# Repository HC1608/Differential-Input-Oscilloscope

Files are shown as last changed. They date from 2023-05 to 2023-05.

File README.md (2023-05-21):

# Differential-Input-Oscilloscope
Unlike a single-ended oscilloscope which can measure only the potential difference between the Ground and a node, it can measure the voltage difference between any two nodes and significant work has been done to make a current sensor that does not draw any current into it.
It is highly portable and can work using normal 5V mobile charger.

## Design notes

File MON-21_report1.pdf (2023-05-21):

# DSO

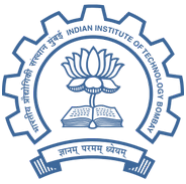
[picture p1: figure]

# Design Review Report

## EE344: Electronic Design Lab

## Faculty Mentor: Prof. PC Pandey Faculty Mentor: Prof. Joseph John

Group: MON-21
TA/RA Guide: Sanskar, Omkar

Group members:
1) Harsh Choudhary (200070023)
2) Harsh Lulla (200070024)
3) Abhinav Ghunawat (200070002)

# Index

Particulars | Page no.
Goal | 3
Block diagram | 4
Work Distribution | 5
Common b/w different groups | 6
Differences among different groups | 6
Bill of material | 7

### EE344 Electronic Design Lab Project Report, EE Dept, IIT Bombay

## 1)Description of Design

### 1.1 Goal of the project

The purpose of this project is to build a two-channel oscilloscope. This oscilloscope would then be interfaced with an application via Bluetooth/Wi-Fi to see the input waveforms inside
the application. The oscilloscope would have protection circuits to prevent voltage and current from going beyond a certain threshold for the safety of the equipment. It would use the ADC of the microcontroller to convert the analog signals to the digital domain. It would also have scaling circuits to appropriately scale up(or down) the signal for display. Finally, it would be connected to a microcontroller and the module to send
the samples to the application. The application would display the waveform along with the
amplitude and frequency. There would be additional circuitry for triggering as well.
We plan to demonstrate that our oscilloscope can display the supplied signals with proper scaling and triggering on the laptop.

### 1.2 Block Diagram

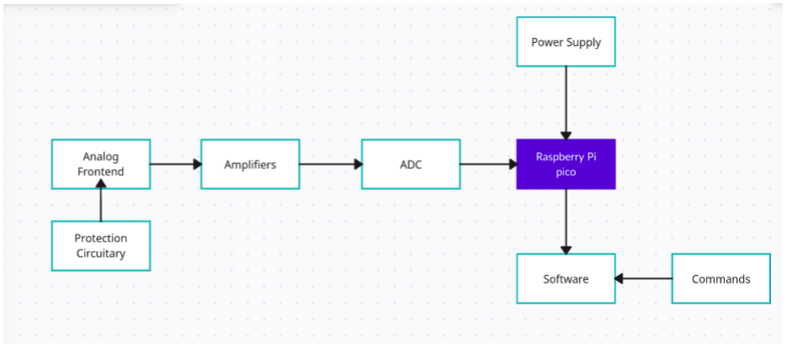
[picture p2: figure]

## 2)Project Description

Description of various parts of the project is as follows:

### 2.1 Input

Measurements shall be taken using a standard BNC connector probe as used for DSOs. Hence, a probe receptacle shall be used to connect to the probe. The standard Input impedance of almost 1MΩ and 120pF in parallel shall be connected.
- For measuring differential voltage we would be using a probe with 3 wires( positive, negative, and ground). Here, the user will have to connect it to the ground separately and there will be two such voltage probes.
- For measuring differential current we would be using probes each with 2 wires (positive and negative)

### 2.2 Protection circuit

A zener diode with necessary breakdown voltage connected back to back across the input terminals can be used for overvoltage protection. Overcurrent protection can be implemented using elements as simple as a Fuse of appropriate rating once the total current required is calculated for the entire circuit.

- We have selected the 1N4733A Zener diode to protect the circuit from voltages more than 20V
- We will be using Fuse which would protect the circuit from higher currents.

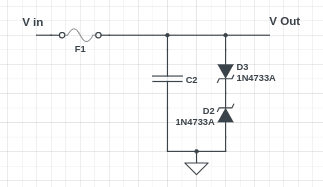
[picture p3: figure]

Figure: Protection Circuit

### 2.3 I-to-V conversion

We will use INA210 for this purpose, it is a bidirectional high-precision current sense amplifier, meaning it can measure both positive and negative currents. They have differential input pins (INA+ and INA-) for the current source and provide a voltage output proportional to the input current. It takes input power supply from 2.7V to 26V.
So, we have decided the following circuitry with Vout = (IRs)xGain + Vref

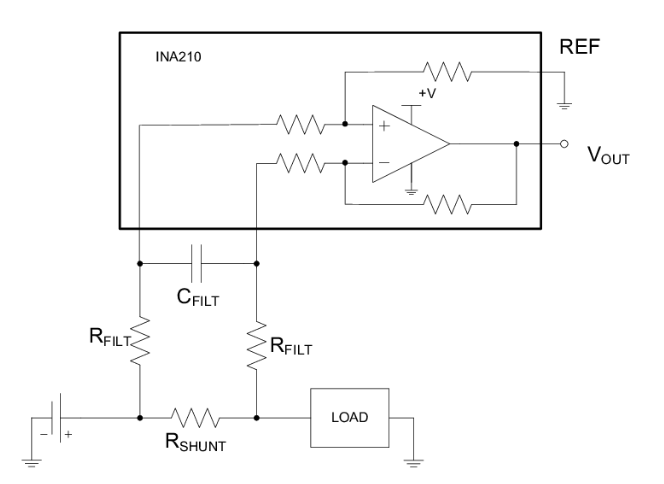
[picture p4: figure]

Figure: Bi-directional I to V conversion using INA210

### 2.4 Scaling

We have planned to use an instrumentation amplifier for amplification and to take the difference of two voltages. INA326 can be used for this purpose. It is a precision instrumentation amplifier and works with a single-sided source voltage of 5V. Its gain is given by (R3/R2)((2R1+Rgain)/Rgain).

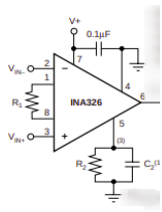
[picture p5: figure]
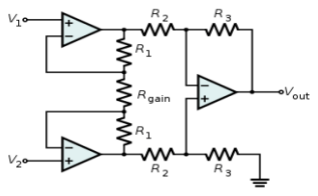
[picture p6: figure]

Figure: Instrumentation Amplifier | Figure: INA326 Circuit

X, Y Scaling will be done using hardware and not software as software receives values converted using ADC and thus it has quantization error. Further scaling it would scale up the error term also.
The value of gain will be transmitted from the software to the microcontroller and it will vary the scaling factor in the hardware accordingly.

### 2.5 Microcontroller

Microcontroller will be used for transmitting the signal from hardware to software using a wireless medium (Bluetooth/Wi-Fi) or using wire. First, it will convert analog input from the hardware to digital. Also, the Computer will communicate values of X-scale, Y-scale, and channel settings to the microcontroller, based on them, it will set the gain of the amplifier and control the multiplexer to give values of the required channels to ADC.

We have decided to use Raspberry Pi Pico for this purpose
- We will be providing power to the microcontroller using a mobile phone charger
- It has an in-built 12-bit SAR type ADC. Hence, the digital value between 0-4095 will be mapped to analog values.
- Communication will be bi-directional (in duplex mode), we will use Bluetooth/Wi-Fi/Type-C cable for connecting the devices.
- It is a dual-core Arm Cortex-M0+ processor and provides flexible clock and power management.
- The board features 26 GPIO pins, including 2 analog inputs, 2 pulse width modulation (PWM) outputs, and 2 serial peripheral interface (SPI) interfaces
- It supports microPython, which is python library made for microcontrollers

### 2.6 Triggering and Frequency Detection

We will initially do edge triggering and later as per the availability of time we can implement more triggers and also can use algorithms like peak detector or level crossing for frequency detection in sinusoidal and square waves as an additional feature.

### 2.7 Power Management

- We will supply power to the microcontroller using an adapter.
- To save power, we will transmit a signal from the multiplexer to the ADC only when it is turned from the

software.

### 2.8 Interfacing Application

We are planning to use an application based on python. Data will be received from Bluetooth/Wi-fi and would be processed to reconstruct the given signal. The triggering mechanism will be applied from the software itself and other features which will be implemented are:
1. Voltage-scaling (Sending gain value from GUI to the microcontroller)
2. Time Scaling
3. Trigger-Mode
4. X and Y Shift
5. Voltage/Current mode Selector

## 3. Weekly Targets and work distribution

The work distribution according to past experience and interest will be Harsh Choudhary for analog and software, Harsh Lulla for microcontroller and analog, and Abhinav for PCB and packaging. Power Management will be handled by all three of us.

A tentative schedule for throughout the semester is as follows:

1. Week 1: February 1 - February 7
We will have submitted the bill of materials and the components will be procured this week. Meanwhile, we will start with the schematic circuit diagrams for the ADC data transfer and the USB+Bluetooth interfacing with the microcontroller. We will also design the protection circuitry
2. Week 2: February 8 - February 14
After sourcing the components, we will start building the basic analog protection circuit, and we will work on the circuit that amplifies and attenuates the input signal. We will build the I-V conversion circuit on the breadboard. Harsh L will work on USB and Bluetooth interfacing with the microcontroller.
- Milestone: February 15 - Schematics and preliminary analysis(breadboard) review
3. Week 3: February 28 – March 6
Harsh L will start interfacing the Pico with the laptop and the ADC conversion of the signals. We will primarily work on wireless communication through Bluetooth and wired communication using USB. Harsh C will start creating the translation and scaling features on the oscilloscope display. Abhinav will initialize the work on the PCB design. We will all work on studying the different conditions the DSO will be subject to in various current and voltage applications.
4. Week 4: March 7 – March 13
Harsh L will work on the anti-aliasing filter circuit which will incorporate the sampling rate set by the user to remove higher frequency noise on the display. Harsh C will work on interpreting the signal data on the display. Abhinav will work on estimating the power consumption of the circuit and finalize the PCB design.
- Milestone: March 15 - Schematics and preliminary analysis(breadboard) review
5. Week 5: March 16 – March 22
We will collectively design packaging for the PCB design and start wrapping up the documentation of the final product. We will test the product under different conditions and make sure each subsystem is working nominally.
- Milestone: March 24 – Initial subsystem testing review – 1
- Milestone: April 5 – Individual subsystem testing review - 2

## 4. Common and different between groups

The additional feature which our group is implementing is an anti-aliasing filter which uses the Nyquist criteria to filter out higher frequency components of the differential signal. This is a challenging task as this requires us to set the cut-off frequency of the bandpass filter to be variable as the sample rate itself is variable. We will need to build an active low-pass filter circuit with variable cut-off frequency for this task.

There are two other groups doing the same project. We will collectively discuss and build upon each other’s shortcomings. Our basic hardware circuit should be similar to the ones developed by the other groups.

One group is implementing the auto-set feature. This automatically adjusts the x-scale and y-scale based on the input signals applied, and the other group is implementing reverse Nyquist criteria where a lower bound of the frequency spectrum is applied. This, however, introduces a challenge as the signal must be sampled in a fixed time called the aperture time.

## 5. Bill of materials (BOM)

Initial sketch of our Bill of material is as follows:

Item | Quantity | Unit Price
Microcontroller (Raspberry pi pico) | 1 | Rs 590
Instrumentation Amplifier (INA 326) (https://in.rsdelivers.com/product/texas-instruments/ina326ea/250/ina326ea/250-texas-instruments-instrumentation-amplifier-27/1977178) | 2 | Rs 285
4:1 Analog Multiplexer(MC14066BDG) (https://in.element14.com/on-semiconductor/mc14066bdg/4000-cmos-smd-4066-soic14-15v/dp/9666443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) | | | 6 | Rs 57
Op Amp(LM358) | | | 4 | Rs. 225
I- to-V Converter (INA 210) (https://www.digikey.in/en/products/detail/texas-instruments/INA210CIDCKR/7312789) | 2 | Rs 130
Diode (1N4747A) (https://in.element14.com/multicomp-pro/1n4747a/zener-diode-1w-20v-do-41/dp/2132575?st=zener%20diode) | 8 | Rs 6

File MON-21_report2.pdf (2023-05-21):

# DSO

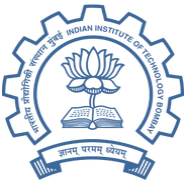
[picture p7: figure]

# Milestone 2 Report

# EE344: Electronic Design Lab

## Faculty Mentor: Prof. PC Pandey Faculty Mentor: Prof. Joseph John

### Group: MON-21 TA/RA Guide: Sanskar, Omkar

### Group members: 1) Harsh Choudhary (200070023) 2) Harsh Lulla (200070024) 3) Abhinav Ghunawat (200070002)

# Index

Particulars | Page no.
Circuit Schematic | 3
Justification for component selection | 4
Principle of operation for each subsystem | 4
Risk Mitigation | 5
Bill of material | 5

## EE344 Electronic Design Lab Project Report, EE Dept, IIT Bombay

# 1)Circuit Schematic

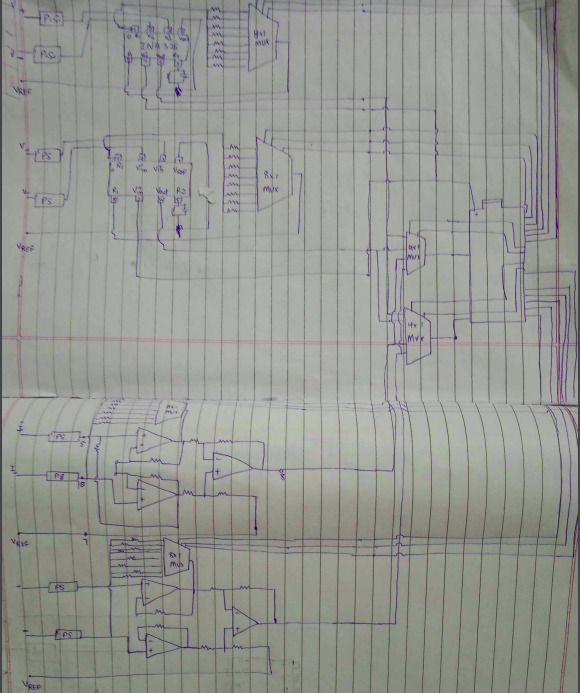
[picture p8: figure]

Figure: Hand Drawn Circuit

### Protection circuit(PS)


Figure: Protection Circuit

# 2)Justification for component selection

- 1N4747A: We have chosen a voltage range of 20 Volts for our oscilloscope and it is a commonly used 20V zener diode
- INA101: it is high precision current sense amplifier
- INA326: popularly used instrumentation amplifier, will be used for measuring differential voltage and scaling it
- CD74HC4051M: 8x1 analog MUX used for receiving digital input from the microcontroller and selecting the corresponding resistor for scaling the output
- MC14066BDG: 4x1 analog MUX for selecting the current/voltage mode
- Raspberry pi pico

# 3)Principle of operation for each subsystem

3.1 Protection Circuitry: Zener diodes with necessary breakdown voltage connected back to back across the input terminals are used for overvoltage protection. Overcurrent protection can be implemented using elements as simple as a Fuse of appropriate rating once the total current required is calculated for the entire circuit.

3.2 Amplifying the differential Voltage: The instrumentation amplifier takes the differential voltage input and A zener diode with necessary breakdown voltage connected back to back across the input terminals can be used for overvoltage protection. Overcurrent protection can be implemented using elements as simple as a Fuse of appropriate rating once the total current required is calculated for the entire circuit and scaled them as per the given commands. its gain is given by 2R2/R1

### 3.3 I-to-v conversion: We use INA101 IC for this purpose

3.4 Transmission: We will be going with Bluetooth to transmit data from the microcontroller to laptop

### 3.5 Software: It will be python based simple GUI to input commands and give the output

# 4)Risk mitigation

- There can be issues in communication and we will try different methods like bluetooth2.0 and other versions, ESP32 module for Wifi communication
- There can be issues in current amplifications as it is a new application and we can try to use different ICs

# 5. Bill of materials (BOM)

Updated Bill of material is as follows:

Item | Unit Price
Microcontroller (Raspberry pi pico) | Rs 590
Instrumentation Amplifier (INA 326) (https://in.rsdelivers.com/product/texas-instruments/ina326ea/250/ina326ea/250-texas-instruments-instrumentation-amplifier-27/1977178) | Rs 285
4:1 Analog Multiplexer(MC14066BDG) (https://in.element14.com/on-semiconductor/mc14066bdg/4000-cmos-smd-4066-soic14-15v/dp/9666443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) | | Rs 57
8:1 Analog Multiplexer | | Rs 300
I- to-V Converter (INA101) | Rs 130
Diode (1N4747A) (https://in.element14.com/multicomp-pro/1n4747a/zener-diode-1w-20v-do-41/dp/2132575?st=zener%20diode) | Rs 6

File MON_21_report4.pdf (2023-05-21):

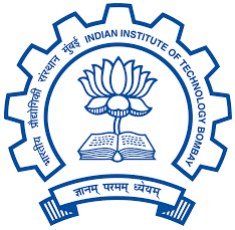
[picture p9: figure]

## Indian Institute of Technology, Bombay Department of Electrical Engineering

EE 344

## Electronic Devices Lab Milestone 3 Initial subsystem testing review

## DSO

Submitted by - | Guided by -
Abhinav Ghunawat | Prof. Joseph John
Harsh Lulla | Prof. PC Pandey
Harsh Choudhary

## Contents

1 Design | 3
2 Abstract and Motivation | 8
3 Results and Observations | 8
4 | Test Results | 9
5 Conclusions and Future Work | 11
6 Important Links | 11
7 References | 11

## 1 Design

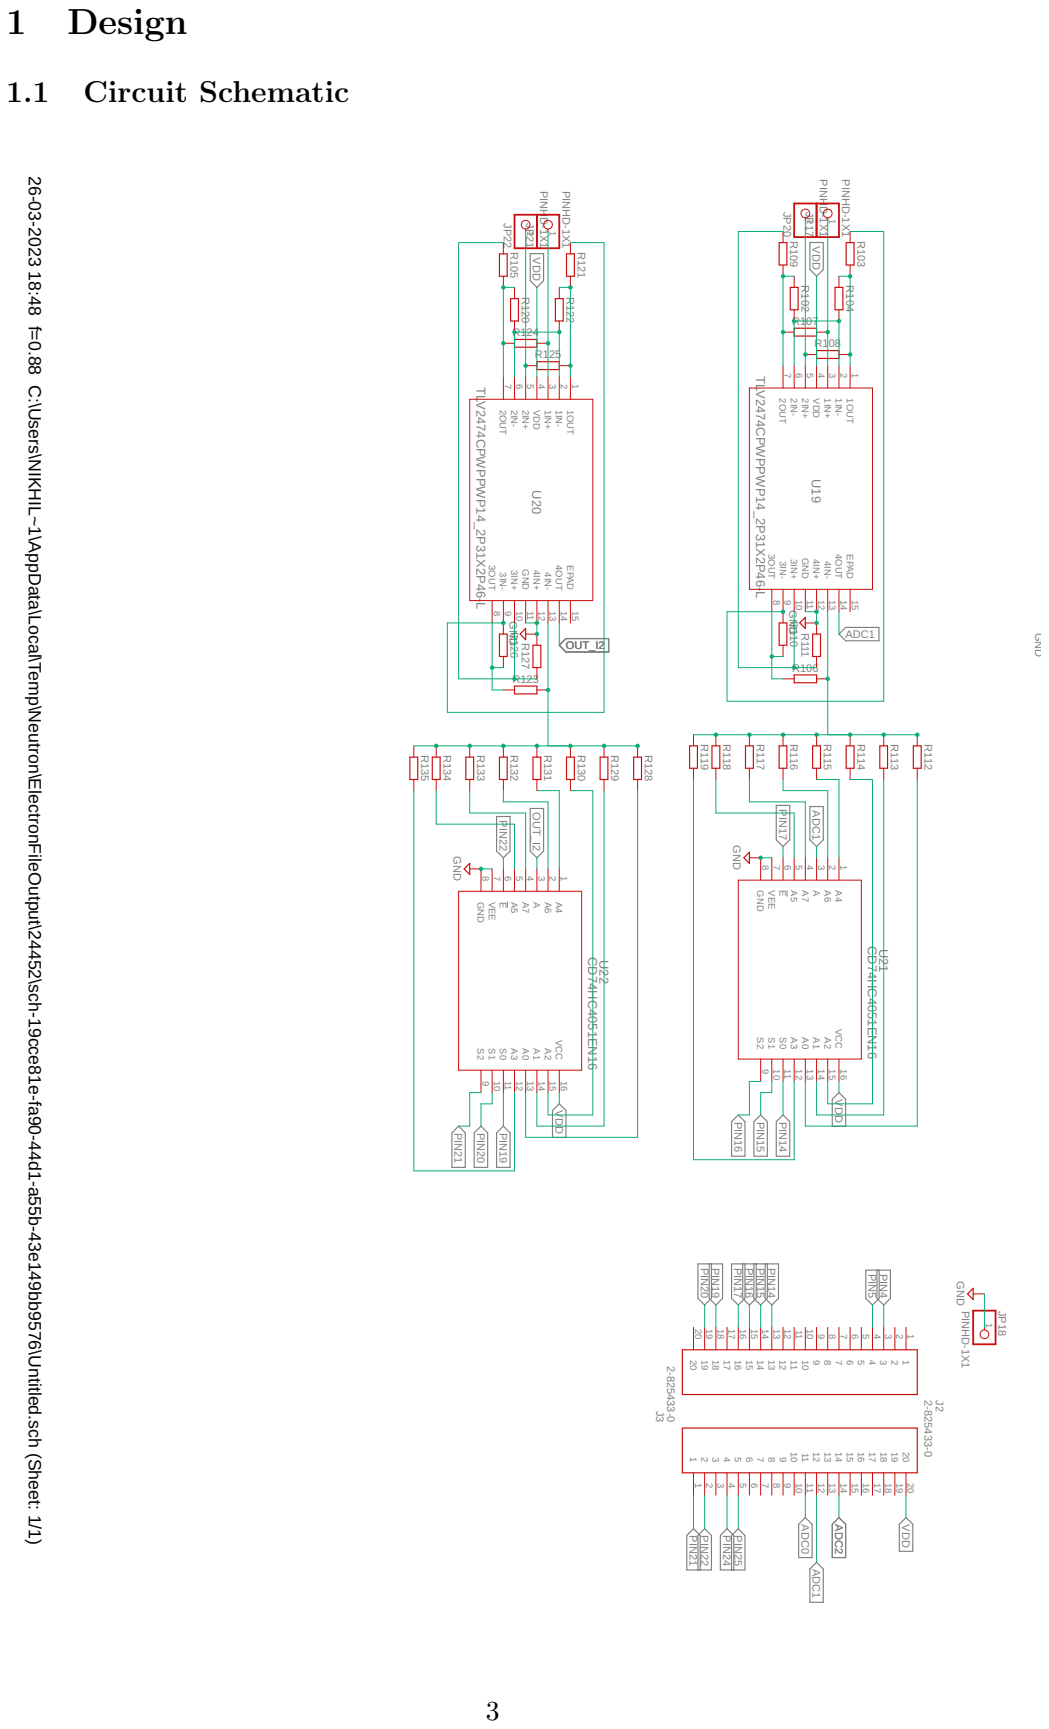
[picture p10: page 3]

26-03-2023 18:48 f=0.88 C:\Users\NIKHIL~1\AppData\Local\Temp\Neutron\ElectronFileOutput\24452\sch-19cce81e-fa90-44d1-a55b-43e149bb9576\Untitled.sch (Sheet: 1/1)

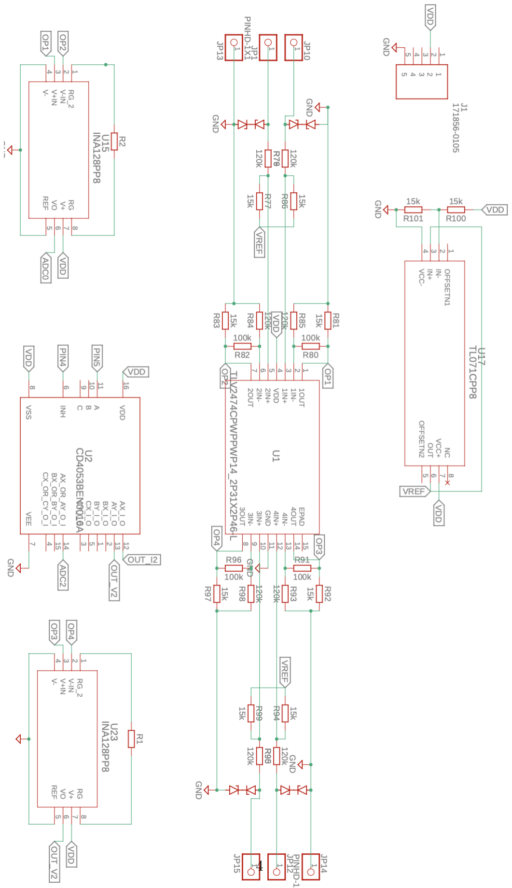
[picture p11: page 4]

### 1.2 PCB Layout

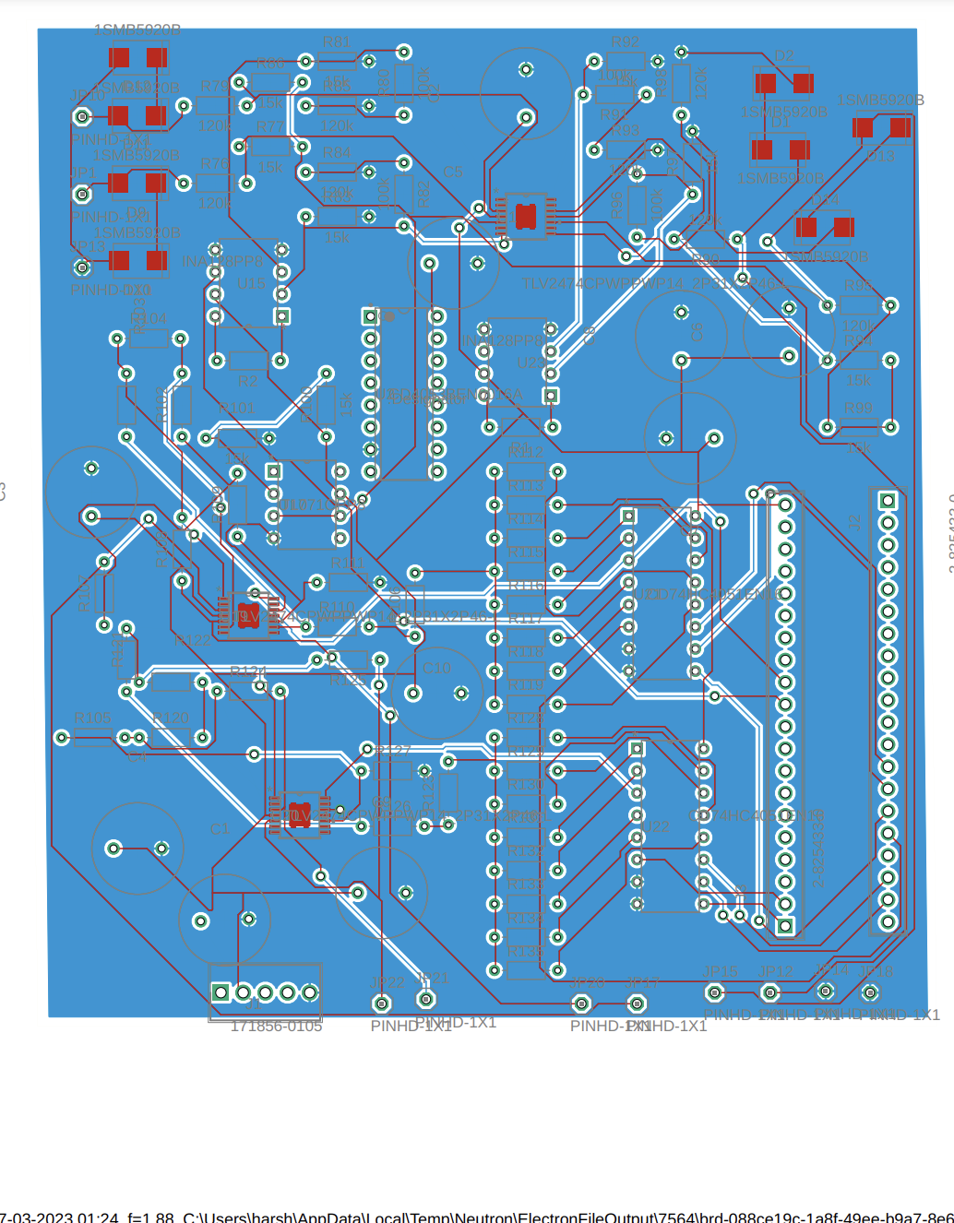
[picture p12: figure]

Figure 1:

### 1.3 CAD Design

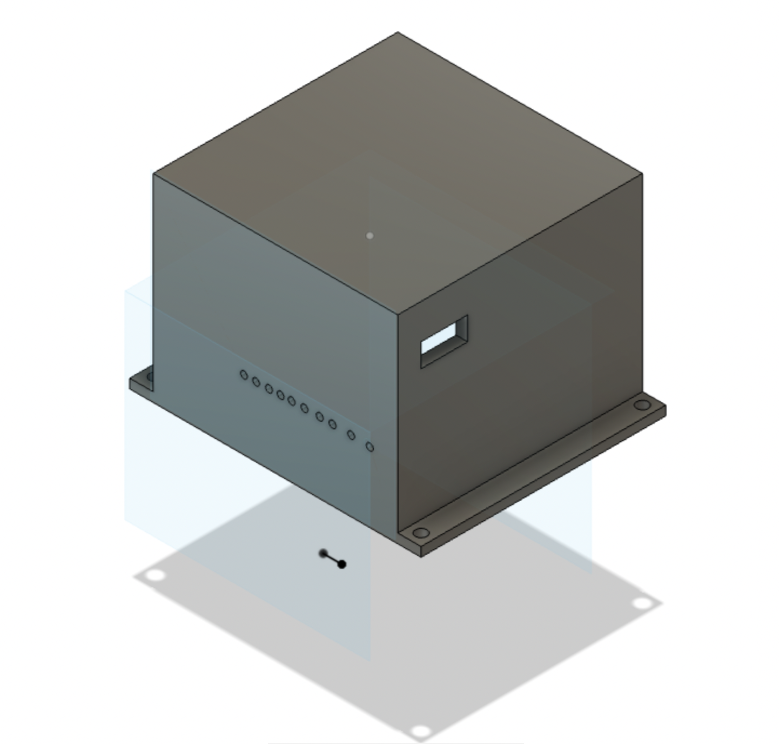
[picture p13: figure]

Figure 2: Home View

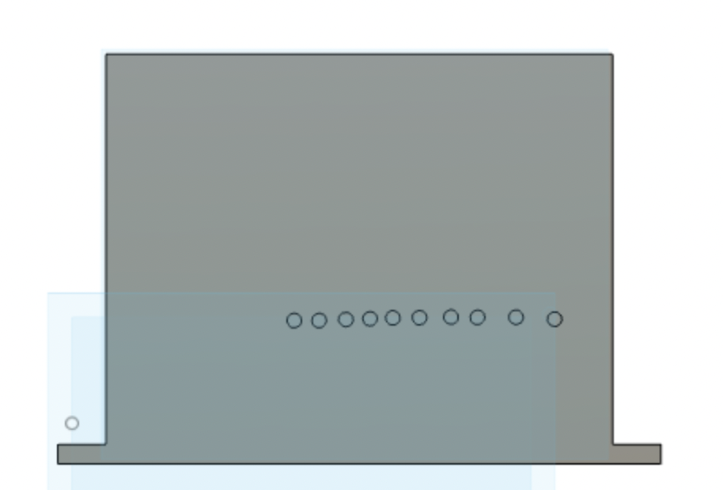
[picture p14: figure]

Figure 3: Front View

### 1.4 GUI

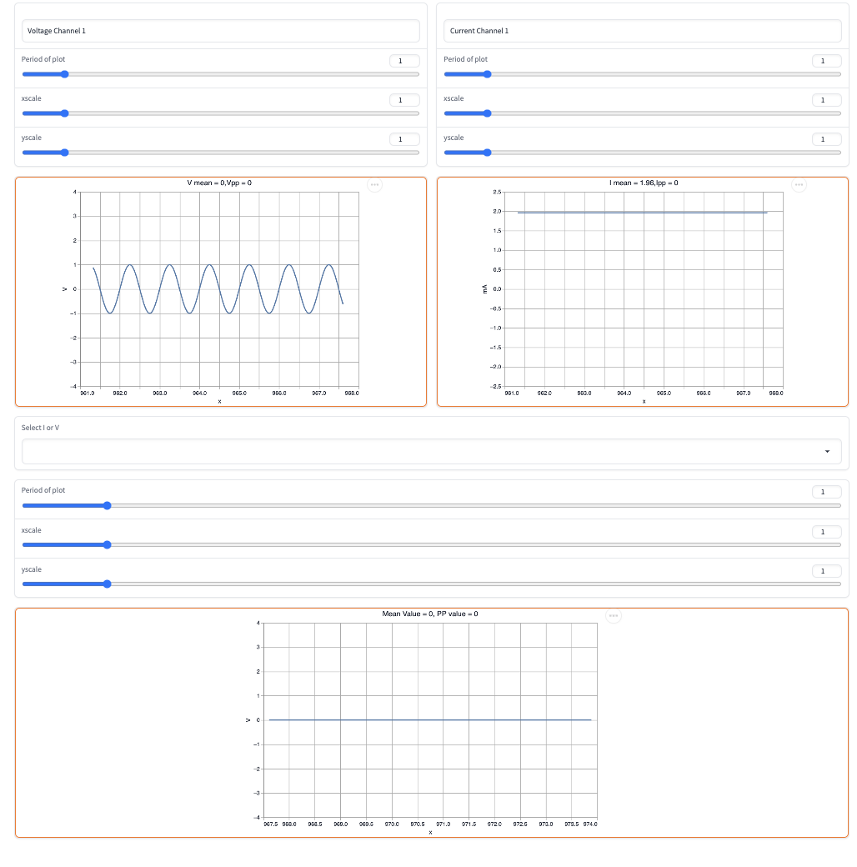
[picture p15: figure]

Figure 4: Web Based GUI

### 1.5 Bill Of Material

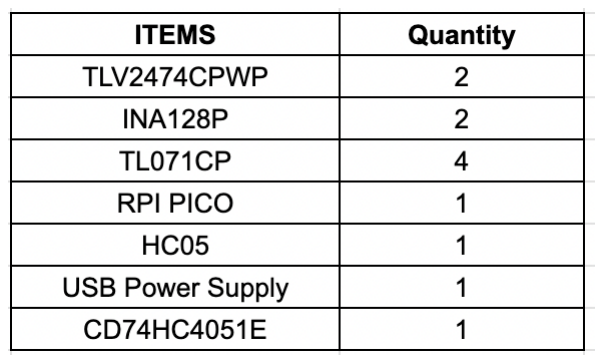
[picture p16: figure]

Figure 5: Bill Of Material extracted from Fusion360

### 1.6 Block Diagram

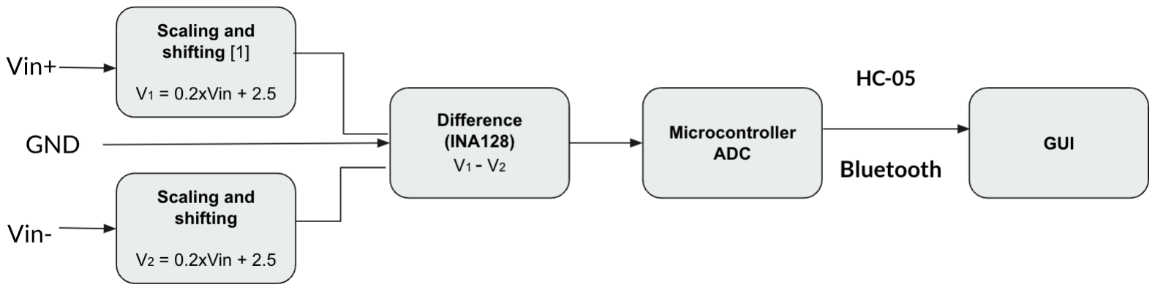
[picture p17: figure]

Figure 6: Block Diagram for Differential Voltage Input

## 2 Abstract and Motivation

Generally, Oscilloscope are bulky and can measure only single-sided voltage, We planned to make portable, Bluetooth-based oscilloscopes for differential inputs

Oscilloscope can not measure current, thus in this project, we planned to measure differential current and voltage using the device

It gives good exposure to different aspects of different fields including Analog frontend Designing, microcontroller programming, GUI designing, Bluetooth Communication, PCB designing and 3-D packaging

## 3 Results and Observations

We targetted to achieve the following Results

- Differential Input Voltage Range: -4V to 4V
- Differential Currential Sensing: 2.5mA

- Accuracy of more than 0.2V, 0.15mA
- 5V USB power supply
- Web Based GUI
- 2 Differential Current Inputs
- 2 Differential Voltage Inputs

We were able to achieve 5 out of them

- Differential Input Voltage Range: -4V to 4V
- Accuracy of more than 0.2V
- 5V USB Power Supply
- Web-Based GUI
- 2 Differential Voltage Inputs

## 4 Test Results

### 4.1 Voltage Scaling and shifting

With this circuit, We have scaled it down by a factor of 1/8 and shifted it by 2.5 volts to bring it in the range of 0 to 5. For this purpose we set resistor values as R2, RF equals 15k ohms, and R1, Rg equals 120k ohms

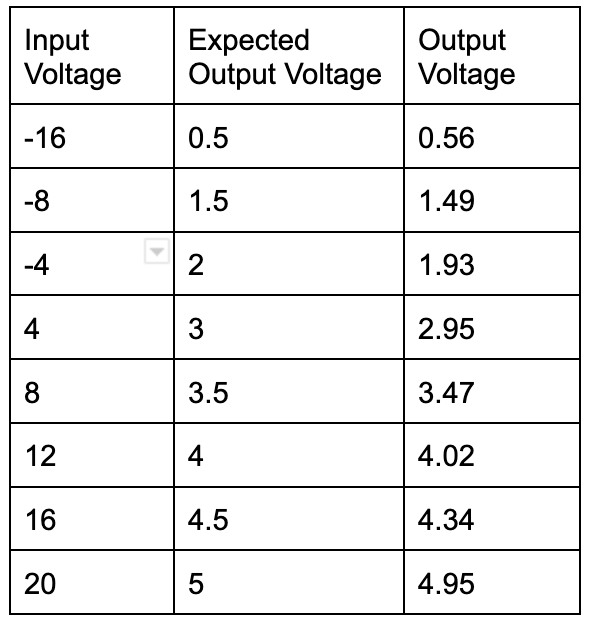
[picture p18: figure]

### 4.2 I to V converter

We are getting unpredictable outputs for this, till now, we have tried it on simulation tool and on breadboard.

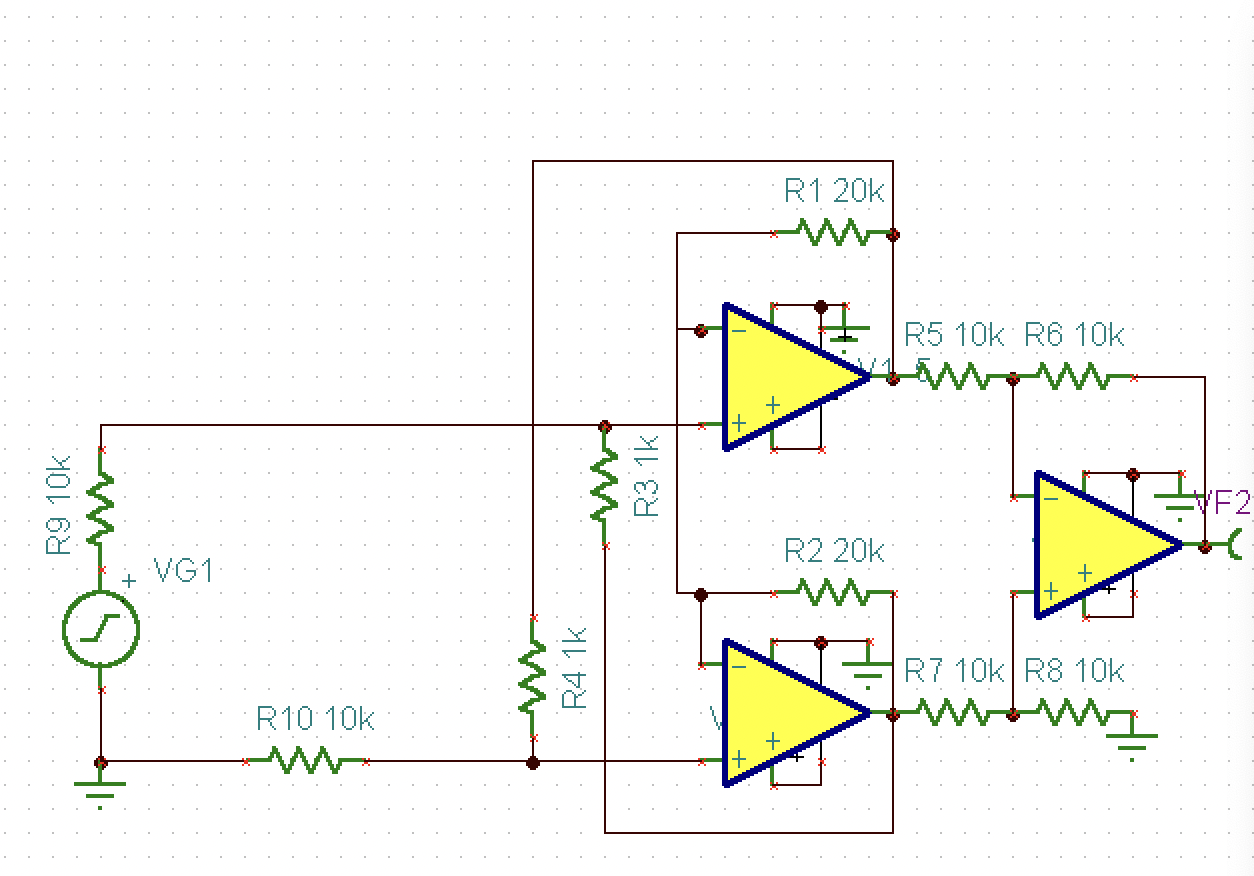
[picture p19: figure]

Figure 7: I to V conversion Circuit for simulation in Tina-Ti

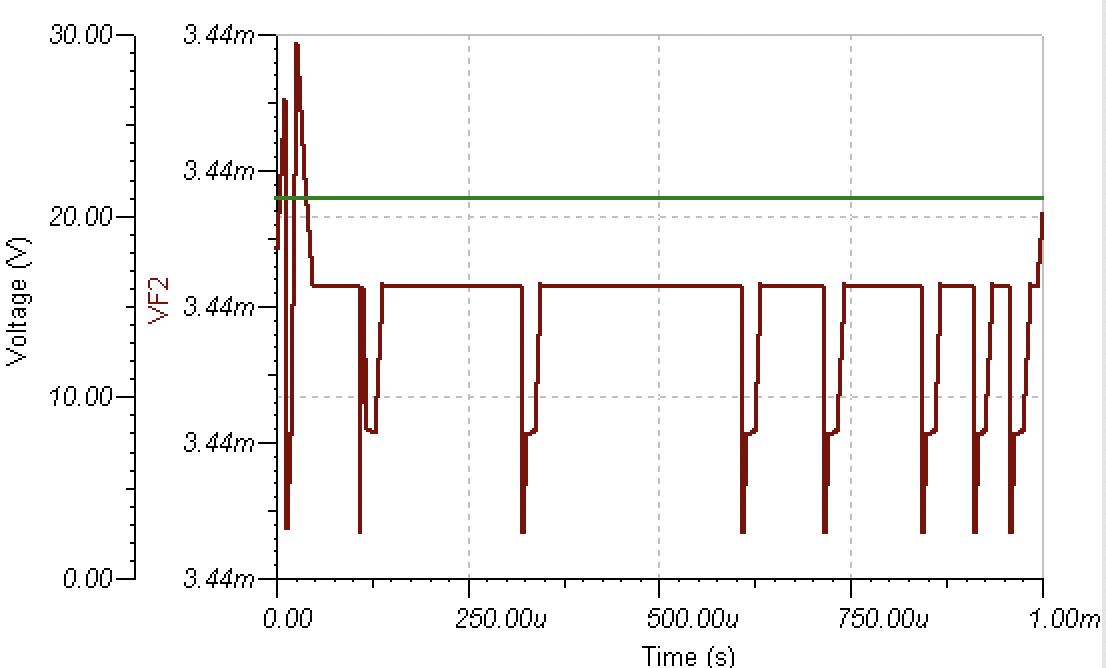
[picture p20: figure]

Figure 8: Simulation Results

### 4.3 Statement of Contribution

- Harsh Choudhary: Designing, Testing, Soldering, Report Making, Schematic Making, Pcb Desgning, Programming Microcontroller, Making GUI
- Abhinav Ghunawat: 3D packaging, Current-Voltage Convertor Testing
- Harsh Lulla: PCB designing, Schematic, Testing

## 5 Conclusions and Future Work

- More than 3 weeks were spent in searching for the I to V converter and it was tested multiple times by all 3 groups but it did not work.
- For using bluetooth module, MacOS is the best option, windows and ubuntu have multiple complications
- We can increase the input voltage range by increasing the voltage of the power supply and using rail-to-rail opamp
- We can increase the accuracy by reducing the scale-down factor and by using digital-pots for scaling

## 6 Important Links

- Github Repository
https://github.com/HC1608/Differential-Input-Oscilloscope
- Demo-Video
https://shorturl.at/ltX04
- Presentation
https://rb.gy/5xjz2

## 7 References

1. Guide for Rpi pico https://projects.raspberrypi.org/en/projects/getting-startedwith-the-pico/3
2. Guide for Bluetooth https://howtomechatronics.com/tutorials/arduino/arduinoand-hc-05-bluetooth-module-tutorial/
3. Guide for Debugging Bluetooth https://www.verizon.com/support/knowledgebase-20605/
4. Documentation for the GUI https://gradio.app/docs/
5. I to V converter from Pg no.156 Burr-Brown-The handbook of linear IC applications
6. I to V conversion using sense resistance, application note of INA 240
7. Voltage Converter and shifter from Section 4-9 Op Amps for Everyone by Ron Mancini

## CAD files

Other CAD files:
3d Packing.f3d

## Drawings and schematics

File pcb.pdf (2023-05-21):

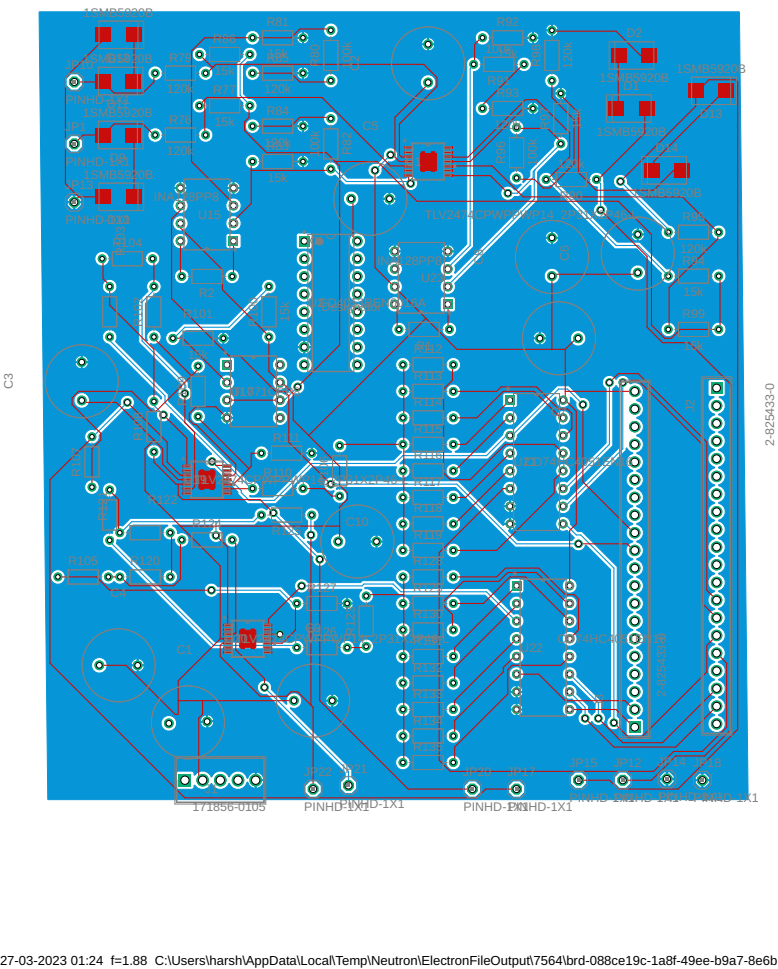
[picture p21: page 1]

27-03-2023 01:24 f=1.88 C:\Users\harsh\AppData\Local\Temp\Neutron\ElectronFileOutput\7564\brd-088ce19c-1a8f-49ee-b9a7-8e6bbd0c6468\PCB routed v1.brd

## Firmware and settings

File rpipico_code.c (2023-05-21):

/*#include "pico/stdlib.h"
#include "hardware/uart.h"
#include "hardware/adc.h"
#include "hardware/timer.h"

#define ADC_PIN 26
#define UART_ID uart0
#define BAUD_RATE 115200
#define BUFFER_SIZE 1024

static uint16_t buffer[BUFFER_SIZE];
static uint16_t buffer_index = 0;
static uint32_t duration_ms = 0;

void timer_callback(void) {
    uint16_t value = adc_read();
    buffer[buffer_index] = value;
    buffer_index = (buffer_index + 1) % BUFFER_SIZE;
}

void uart_rx_callback() {
    uint8_t data = uart_getc(UART_ID);
    if (data == 'T') {
        // Transmit buffer over UART
        uart_write(UART_ID, buffer, BUFFER_SIZE * sizeof(uint16_t));
    } else if (data == 'D') {
        // Get duration from UART
        uint8_t duration_buffer[4];
        uart_read_blocking(UART_ID, duration_buffer, 4);
        duration_ms = *(uint32_t*)duration_buffer;

        // Reset buffer index and timer interval
        buffer_index = 0;
        uint32_t timer_interval_us = duration_ms * 1000;

        // Update timer interval
        cancel_alarm(timer_callback);
        add_alarm_in_us(timer_interval_us, timer_callback, true);
    }
}

void uart_tx_callback() {
    // Nothing to do here
}

int main() {
    stdio_init_all();

    // Set up ADC on channel 0
    adc_init();
    adc_gpio_init(ADC_PIN);
    adc_select_input(0);

    // Set up UART with baud rate 115200
    uart_init(UART_ID, BAUD_RATE);
    gpio_set_function(UART_TX_PIN, GPIO_FUNC_UART);
    gpio_set_function(UART_RX_PIN, GPIO_FUNC_UART);
    uart_set_hw_flow(UART_ID, false, false);
    uart_set_format(UART_ID, 8, 1, UART_PARITY_NONE);
    uart_set_fifo_enabled(UART_ID, true);

    // Set up UART interrupt handlers
    uart_set_irq_enables(UART_ID, true, false);
    irq_set_exclusive_handler(UART_ID == uart0 ? UART0_IRQ : UART1_IRQ, uart_rx_callback);
    irq_set_enabled(UART_ID == uart0 ? UART0_IRQ : UART1_IRQ, true);
    irq_set_exclusive_handler(UART_ID == uart0 ? UART0_IRQ : UART1_IRQ, uart_tx_callback);
    irq_set_enabled(UART_ID == uart0 ? UART0_IRQ : UART1_IRQ, true);

    // Set up timer to trigger callback every duration_ms milliseconds
    uint32_t timer_interval_us = duration_ms * 1000;
    add_alarm_in_us(timer_interval_us, timer_callback, true);

    while (1) {
        // Do nothing here
    }

    return 0;
}
*/
#include <stdio.h>
#include "pico/stdlib.h"
#include "hardware/gpio.h"
#include "hardware/adc.h"
#include <string.h>
#include <unistd.h>

#define UART_ID uart0
#define BAUD_RATE 9600

// We are using pins 0 and 1, but see the GPIO function select table in the
// datasheet for information on which other pins can be used.
#define UART_TX_PIN 0
#define UART_RX_PIN 1

const uint LED_PIN = 25;
#define BUFFER_SIZE 250


float values1[BUFFER_SIZE];
float values2[BUFFER_SIZE];

int main() {
    stdio_init_all();
    
    uart_init(UART_ID, BAUD_RATE);
    gpio_init(LED_PIN);
    gpio_set_dir(LED_PIN, GPIO_OUT);
    
    gpio_set_function(UART_TX_PIN, GPIO_FUNC_UART);
    gpio_set_function(UART_RX_PIN, GPIO_FUNC_UART);
    
   // printf("ADC Example, measuring GPIO26\n");

    adc_init();

    // Make sure GPIO is high-impedance, no pullups etc
    adc_gpio_init(26);
    adc_gpio_init(27);
    // Select ADC input 0 (GPIO26)
    //adc_select_input(0);
    int temp=0;
    
    while (1) {
        //gpio_put(LED_PIN, 0);
        //sleep_ms(250);
        //gpio_put(LED_PIN, 1);
        //printf("Hello World\n");
        //sleep_ms(1000);
        const float conversion_factor = 3.3f / (1 << 12);
        adc_select_input(0);
        uint16_t result1 = adc_read();
        adc_select_input(1);
        uint16_t result2 = adc_read();
        //printf("Raw value: 0x%03x, voltage: %f V\n", result, result * conversion_factor);
        //uart_puts(UART_ID, "Bluetooth working!\n");
        //sleep_ms(1);
        values1[temp]=result1 * conversion_factor;
        values2[temp]=result2 * conversion_factor;
        temp+=1;

        if(temp%BUFFER_SIZE==0){
            //int t;
            //scanf("%d",t);
            printf("CH1");
            uart_puts(UART_ID, "CH1 ");
            for(int i=0;i<BUFFER_SIZE;i++){
              //  write(1,&values[i],sizeof(float));
                char buf[6];
                gcvt(values1[i], 6, buf);
                printf(" %f", values1[i]);
                uart_puts(UART_ID, buf);
                uart_puts(UART_ID, " ");
            }
            //char c = 'p';
            //fwrite(&c, sizeof(char), 1, stdout);
            //char *c = "Hello world";
            //write (1,c,strlen(c)+1);
            printf("\n");
            uart_puts(UART_ID, "\n");

            printf("CH2");
            uart_puts(UART_ID, "CH2 ");
            for(int i=0;i<BUFFER_SIZE;i++){
                char buf[6];
                gcvt(values2[i], 6, buf);
                printf(" %f", values2[i]);
                uart_puts(UART_ID, buf);
                uart_puts(UART_ID, " ");
            }
            printf("\n");
            uart_puts(UART_ID, "\n");
            temp=0;
            sleep_ms(1);
        }
    }
}
